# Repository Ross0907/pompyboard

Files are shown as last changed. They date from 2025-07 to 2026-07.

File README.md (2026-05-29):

# Wonkle

WBP logo



Wonkle builds gaming hardware such as tablets and keypads for gamers.
Source code, 3D models, schematics, etc. are available under
[OSI-Approved Software and Hardware Licenses](https://opensource.org/licenses). We welcome everyone
to contribute and join us in our quest to make the best hardware for our fellow gamers.

## [Frequently Asked Questions](https://docs.wonkle.io/faq.html)

## Star History

Star History Chart (https://www.star-history.com/#wonkleio/wonkle&type=date&legend=top-left)

## Contributors

Wonkle is built by people like you.

profile pictures of contributors (https://github.com/wonkleio/wonkle/graphs/contributors)

## License

Different parts of the project are available under different licenses.

All image, audio, and other resources are, unless otherwise specified, available under
[`CC-BY-4.0`](https://spdx.org/licenses/CC-BY-4.0.html).

The hardware designs are, unless otherwise specified, available under
[`CERN-OHL-S-2.0`](https://spdx.org/licenses/CERN-OHL-S-2.0.html).

All other code are, unless otherwise specified, available under
[`MIT`](https://spdx.org/licenses/MIT.html).

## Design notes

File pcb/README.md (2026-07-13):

# PCB

Designed with [KiCad][kicad].

## Designing

- Every PCB is designed with KiCad `v10.0.3`.
- you can learn more about each of the components and read their documentations at
  [`docs/components`](./docs/components/README.md).
  Running `bun run gen-docs` will download PDF documentations.

## Manufacturing

Both prototype and production PCB is manufactured by [JLCPCB][jlcpcb].

### Steps

1. Install [KiCad][kicad].
2. Install the [Fabrication Toolkit][fab-toolkit] plugin.
3. "Generate" production files using the plugin with default settings.
4. Go to [jlcpcb.com][jlcpcb] and click "Add gerber file"
5. Select `pcb/production/wonkle.zip`
6. Configure PCB (you will get 5 pcb of which 2 have components soldered)
   - PCB Specifications
     - PCB Thickness - 1.0mm
     - Surface Finish - LeadFree HASL (health is important boiz)
   - High-spec Options
     - Confirm Production file - Yes
     - Mark on PCB - Order Number(Specify Position)
   - PCB Assembly
     - PCBA Qty - minimum is 2
     - Confirm Parts Placement - Yes
     - Advanced
       - Board Cleaning - Yes
7. Press "NEXT"
8. Inspect PCB and press "NEXT" again
9. Upload and process `pcb/production/bom.csv` and `pcb/production/positions.csv`
10. Review the parts and press "NEXT"
11. Fix component placement
    - only J2 (1x4 pin) needs manual edit
12. Select `Research\Education\DIY\Entertainment > DIY Hobby Circuit Board - HS Code 902300` in Quote & Order section. The total price is 137.13 USD as of writing.
13. Press "SAVE TO CART"
14. Select both PCB and PCBA then click "Secure Checkout"
15. Enter shipping info and follow JLCPCB's instruction (e.g. production file confirmation)
16. Wait for a week and you'll receive your very own board!

[kicad]: https://www.kicad.org/
[jlcpcb]: https://jlcpcb.com/
[fab-toolkit]: https://github.com/bennymeg/Fabrication-Toolkit

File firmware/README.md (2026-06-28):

# Wonkle Firmware

## Must read

- https://probe.rs
- https://github.com/stm32-rs/stm32f4xx-hal
- https://github.com/rust-embedded/cortex-m
- https://defmt.ferrous-systems.com
- https://docs.rust-embedded.org/book
- [`pcb/lib/st-stm32f429/README.md`](../pcb/lib/st-stm32f429/README.md)
- (optional) also check
  - https://github.com/rust-lang/rustlings
  - https://www.youtube.com/@therustybits/videos
  - https://doc.rust-lang.org/stable/book

## Setting up

1. Setup development environment with [mise](https://mise.jdx.dev/getting-started.html) and [nix](https://nix.dev/install-nix.html)
   - [IDE integration](https://mise.jdx.dev/ide-integration.html)

## Commands

### Flash and run

See https://probe.rs/docs/tools/probe-rs/ for more information.
See [`./Cargo.toml`](./Cargo.toml) to see available devices.

Pick a device with `-p <package>`:

```bash
cargo run --release -p wonkleboard-mk1-pro
```

Or from inside a device crate:

```bash
cd device/board/mk1/pro
cargo run --release
```

### List USB devices

```bash
lsusb
```

### Show device descriptor

```bash
lsusb -v -d 1209:02d7 # (vid:pid)
```

### Show HID descriptor

You can use https://eleccelerator.com/usbdescreqparser/ to parse the output.

```bash
usbhid-dump -m 1209:02d7 # (vid:pid)
```

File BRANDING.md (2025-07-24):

# Branding Guideline

## Name

- Correct: PompyBoard / Pompyboard / pompyboard
- not correct: pompy board

## Logo

### Colored

WIP

### Black & White

WIP

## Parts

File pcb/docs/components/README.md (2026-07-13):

<!-- This file is generated by ../../scripts/docs.ts. Do not edit manually. -->

# Component docs

## [AH49HSC](./AH49HSC.md)

## [CD74HC4067SM96](./CD74HC4067SM96.md)

## [STM32F429IGT6](./STM32F429IGT6.md)

## [TPS62152RGTR](./TPS62152RGTR.md)

## [USB4085_GF_A](./USB4085_GF_A.md)

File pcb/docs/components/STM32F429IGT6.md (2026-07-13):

---
documents:
  - label: datasheet
    url: https://web.archive.org/web/20260708092521/https://www.st.com/content/ccc/resource/technical/document/datasheet/03/b4/b2/36/4c/72/49/29/DM00071990.pdf/files/DM000719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
    sha256: fc8828e819fb0717f15c125ae31075c2e48d2afe2eb447e5e0cc1784ddf785bb
  - label: reference manual
    url: https://web.archive.org/web/20260708092558/https://www.st.com/content/ccc/resource/technical/document/reference_manual/3d/6d/5a/66/b4/99/40/d4/DM00031020.pdf/files/D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
    sha256: f3ff2322eec21f4e49081f68481b764506eee81dba6031bc767e2f8955b27cca
  - label: ADC application note
    url: https://web.archive.org/web/20260708092521/https://www.st.com/resource/en/application_note/an2834-how-to-optimize-the-adc-accuracy-in-the-stm32-mcus-stmicroelectroni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
    sha256: da96e285ee1e151646b285e8828b3486ed40bf7ca2680620f06ef693be2cd569
  - label: oscillator application note
    url: https://web.archive.org/web/20260708092522/https://www.st.com/resource/en/application_note/an2867-guidelines-for-oscillator-design-on-stm8afals-and-stm32-mcusmpus-st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
    sha256: 1c92e22e215ca66a159c790589d568830c619d14f31193429787902664eae04e
---

# STM32F429IGT6

In case the links have expired, you can search the documents by their id (in parenthesis) at
[st.com](https://www.st.com/).

- [JLCPCB](https://jlcpcb.com/partdetail/STMicroelectronics-STM32F429IGT6/C54328)

## Datasheet (DS9405)

- see table of contents (page 3) for more info
- page 13 - what the document is
- page 19 - board design
- page 20 - block diagram
- page 26 - power supply
- page 41 - USB
- page 42 - GPIO & ADC
- page 48 - pinout diagram
- page 53 - pinout definitions table
- page 86 - memory mapping
- page 93 - max ranges
- page 95 - operating conditions
- page 101 - supply current
- page 118 - external clock
- page 122 - internal clock
- page 129 - memory
- page 131 - electromagnetic safety
- page 135 - IO ports
- page 152 - USB OTG HS
- page 158 - ADC
- page 163 - PCB design guideline
- page 165 - reference voltage
- page 209 - LQFP176 package
- page 224 - thermal
- page 225 - ordering information
- page 229 - USB OTG HS

## Reference manual (RM0090)

- see table of contents (page 2) for more info
- page 59 - Memory
- page 73 - Flash Memory
- page 113 - CRC
- page 116 - Power
- page 151 - RCC
- page 153 - Clock tree
- page 269 - GPIO
- page 304 - DMA
- page 373 - Interrupts & Events
- page 390 - ADC
- page 480 - LCD-TFT Controller
- page 515 - Timers
- page 960 - USART
- page 1228 - USB OTG_FS
- page 1369 - USB OTG_HS
- page 1671 - Debug

## ADC application note

- see table of contents (page 2) for more info

## Oscillator application note

- see table of contents (page 2) for more info

## ADC pins

ADC-capable GPIO pins taken from datasheet Table 10, pages 53-59.

| Pin  | ADC1 | ADC2 | ADC3 | IN  |
| ---- | :--: | :--: | :--: | :-- |
| PA0  |  ✅  |  ✅  |  ✅  | 0 |
| PA1  |  ✅  |  ✅  |  ✅  | 1 |
| PA2  |  ✅  |  ✅  |  ✅  | 2 |
| PA3  |  ✅  |  ✅  |  ✅  | 3 |
| PA4  |  ✅  |  ✅  | | 4 |
| PA5  |  ✅  |  ✅  | | 5 |
| PA6  |  ✅  |  ✅  | | 6 |
| PA7  |  ✅  |  ✅  | | 7 |
| PB0  |  ✅  |  ✅  | | 8 |
| PB1  |  ✅  |  ✅  | | 9 |
| PC0  |  ✅  |  ✅  |  ✅  | 10  |
| PC1  |  ✅  |  ✅  |  ✅  | 11  |
| PC2  |  ✅  |  ✅  |  ✅  | 12  |
| PC3  |  ✅  |  ✅  |  ✅  | 13  |
| PC4  |  ✅  |  ✅  | | 14  |
| PC5  |  ✅  |  ✅  | | 15  |
| PF3  | | |  ✅  | 9 |
| PF4  | | |  ✅  | 14  |
| PF5  | | |  ✅  | 15  |
| PF6  | | |  ✅  | 4 |
| PF7  | | |  ✅  | 5 |
| PF8  | | |  ✅  | 6 |
| PF9  | | |  ✅  | 7 |
| PF10 | | |  ✅  | 8 |

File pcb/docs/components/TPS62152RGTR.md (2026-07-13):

---
documents:
  - label: datasheet
    url: https://www.ti.com/lit/ds/symlink/tps62152.pdf
    sha256: 81e0acf0290ce9d8b54f53af5edd4540a8b69e765809abd9c209f1089777875b
---

# TPS62152RGTR

- [JLCPCB](https://jlcpcb.com/partdetail/TexasInstruments-TPS62152RGTR/C2070611)

## Datasheet

- page 3 - pinout
- page 4 - specifications
- page 18 - application curves
- page 22 - Power-Supply Rejection Ratio (PSRR)
- page 26 - 3.3V 1A example schematic
- page 28 - PCB layout guideline and example

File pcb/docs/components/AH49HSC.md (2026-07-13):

---
documents:
  - label: datasheet
    url: https://jlcpcb.com/api/file/downloadByFileSystemAccessId/8588913960356106240
    sha256: 8531c6d96742387937d8e28dc8df8cf026d0c4049aeb09b5ba732353a892300a
---

# AH49HSC

- [JLCPCB](https://jlcpcb.com/partdetail/PJSEMI-AH49HSC/C510723)

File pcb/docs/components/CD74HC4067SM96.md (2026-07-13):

---
documents:
  - label: datasheet
    url: https://www.ti.com/lit/ds/symlink/cd74hc4067.pdf
    sha256: fa6b802d8ad556b5e13ad05808e3feb5ef3824e0803dab9d12978de9b0e67b24
---

# CD74HC4067SM96

- [JLCPCB](https://jlcpcb.com/partdetail/TexasInstruments-CD74HC4067SM96/C98457)

## Datasheet

- page 1 - pinout
- page 2 - truth table

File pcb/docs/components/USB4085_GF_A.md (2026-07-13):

---
documents:
  - label: datasheet
    url: https://gct.co/download?type=PDFSpecification&name=usb4085-spec.pdf
    sha256: e5e6f4f67ccaee397b33324fde439f7cdd273c5dd9048c48f096aae7029034be
---

# USB4085_GF_A

- [JLCPCB](https://jlcpcb.com/partdetail/8061907-USB4085_GFA/C7095263)

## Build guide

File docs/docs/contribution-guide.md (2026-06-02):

# Contribution Guide

## Project overview

Wonkle projects can be roughly broken down into 5 parts:

- [PCB](https://github.com/wonkleio/wonkle/tree/dev/pcb) - Electronics that powers the device
- [Firmware](https://github.com/wonkleio/wonkle/tree/dev/firmware) - Software that controls the electronics
- [3D models](https://github.com/wonkleio/wonkle/tree/dev/3d) - Designs for the 3D-printed case
- [Driver](https://github.com/wonkleio/OpenTabletDriver) - Device driver that allows you to use the
- [Website](https://github.com/wonkleio/wonkle/tree/dev/web) - Website for purchasing and configuring the device
- [Docs](https://github.com/wonkleio/wonkle/tree/dev/docs) - Information & Resources (hint: You are reading it)

## Setting up development environment

### For tablet driver

1. Clone the git repository
   ```bash
   git clone https://github.com/wonkleio/OpenTabletDriver
   ```
2. Follow [`CONTRIBUTING.md`](https://github.com/wonkleio/OpenTabletDriver/blob/master/CONTRIBUTING.md)
3. Send Pull request to `master` branch when contributing

### For everything else

1. Clone the git repository
   ```bash
   git clone https://github.com/wonkleio/wonkle
   ```
2. Follow `README.md` of the sub-project you want to work on
   (e.g. [`docs/README.md`](https://github.com/wonkleio/wonkle/tree/dev/docs))
3. Send pull request to `dev` branch when contributing

## Contribution standards

### AI

- ✅ OK - Using AI to write code
- ✅ OK - Using AI to help you analyze/understand
- ❌ NOT OK - Using AI to write natural language
  - This applies to, but not limited to code comments, HTML contents,
    documentations, commit messages, and Pull request descriptions
- ❌ NOT OK - Using AI to make slop
  - **1 year ban from the project for repeated violations**
  - Please review your changes before sending a pull request.

### Communication, communication, communication

Remember, people can't read your mind. If you did something amazing and you want others to care
about it, explain your intent and motivation using fact and logic so anyone with three digit IQ can
understand them. You don't necessarily have to dumb things down. Just be clear about it.

### Formatting

All text-based files must be formatted using the correct formatter.
See [`.vscode/settings.json`](https://github.com/wonkleio/wonkle/blob/dev/.vscode/settings.json)
for more info.

### line length

All human-written text files must have 100 characters or less per line unless absolutely necessary.
If you're using vscode, you should see a vertical line (ruler) that shows you where the limit is.

### Commits messages

Commit messages must be specific and concise. Prepend scope if necessary.

For example:

- `remove unused files`
- `firmware: add more test cases for functionName`
- `web: bump packageName version from v6 to v9`

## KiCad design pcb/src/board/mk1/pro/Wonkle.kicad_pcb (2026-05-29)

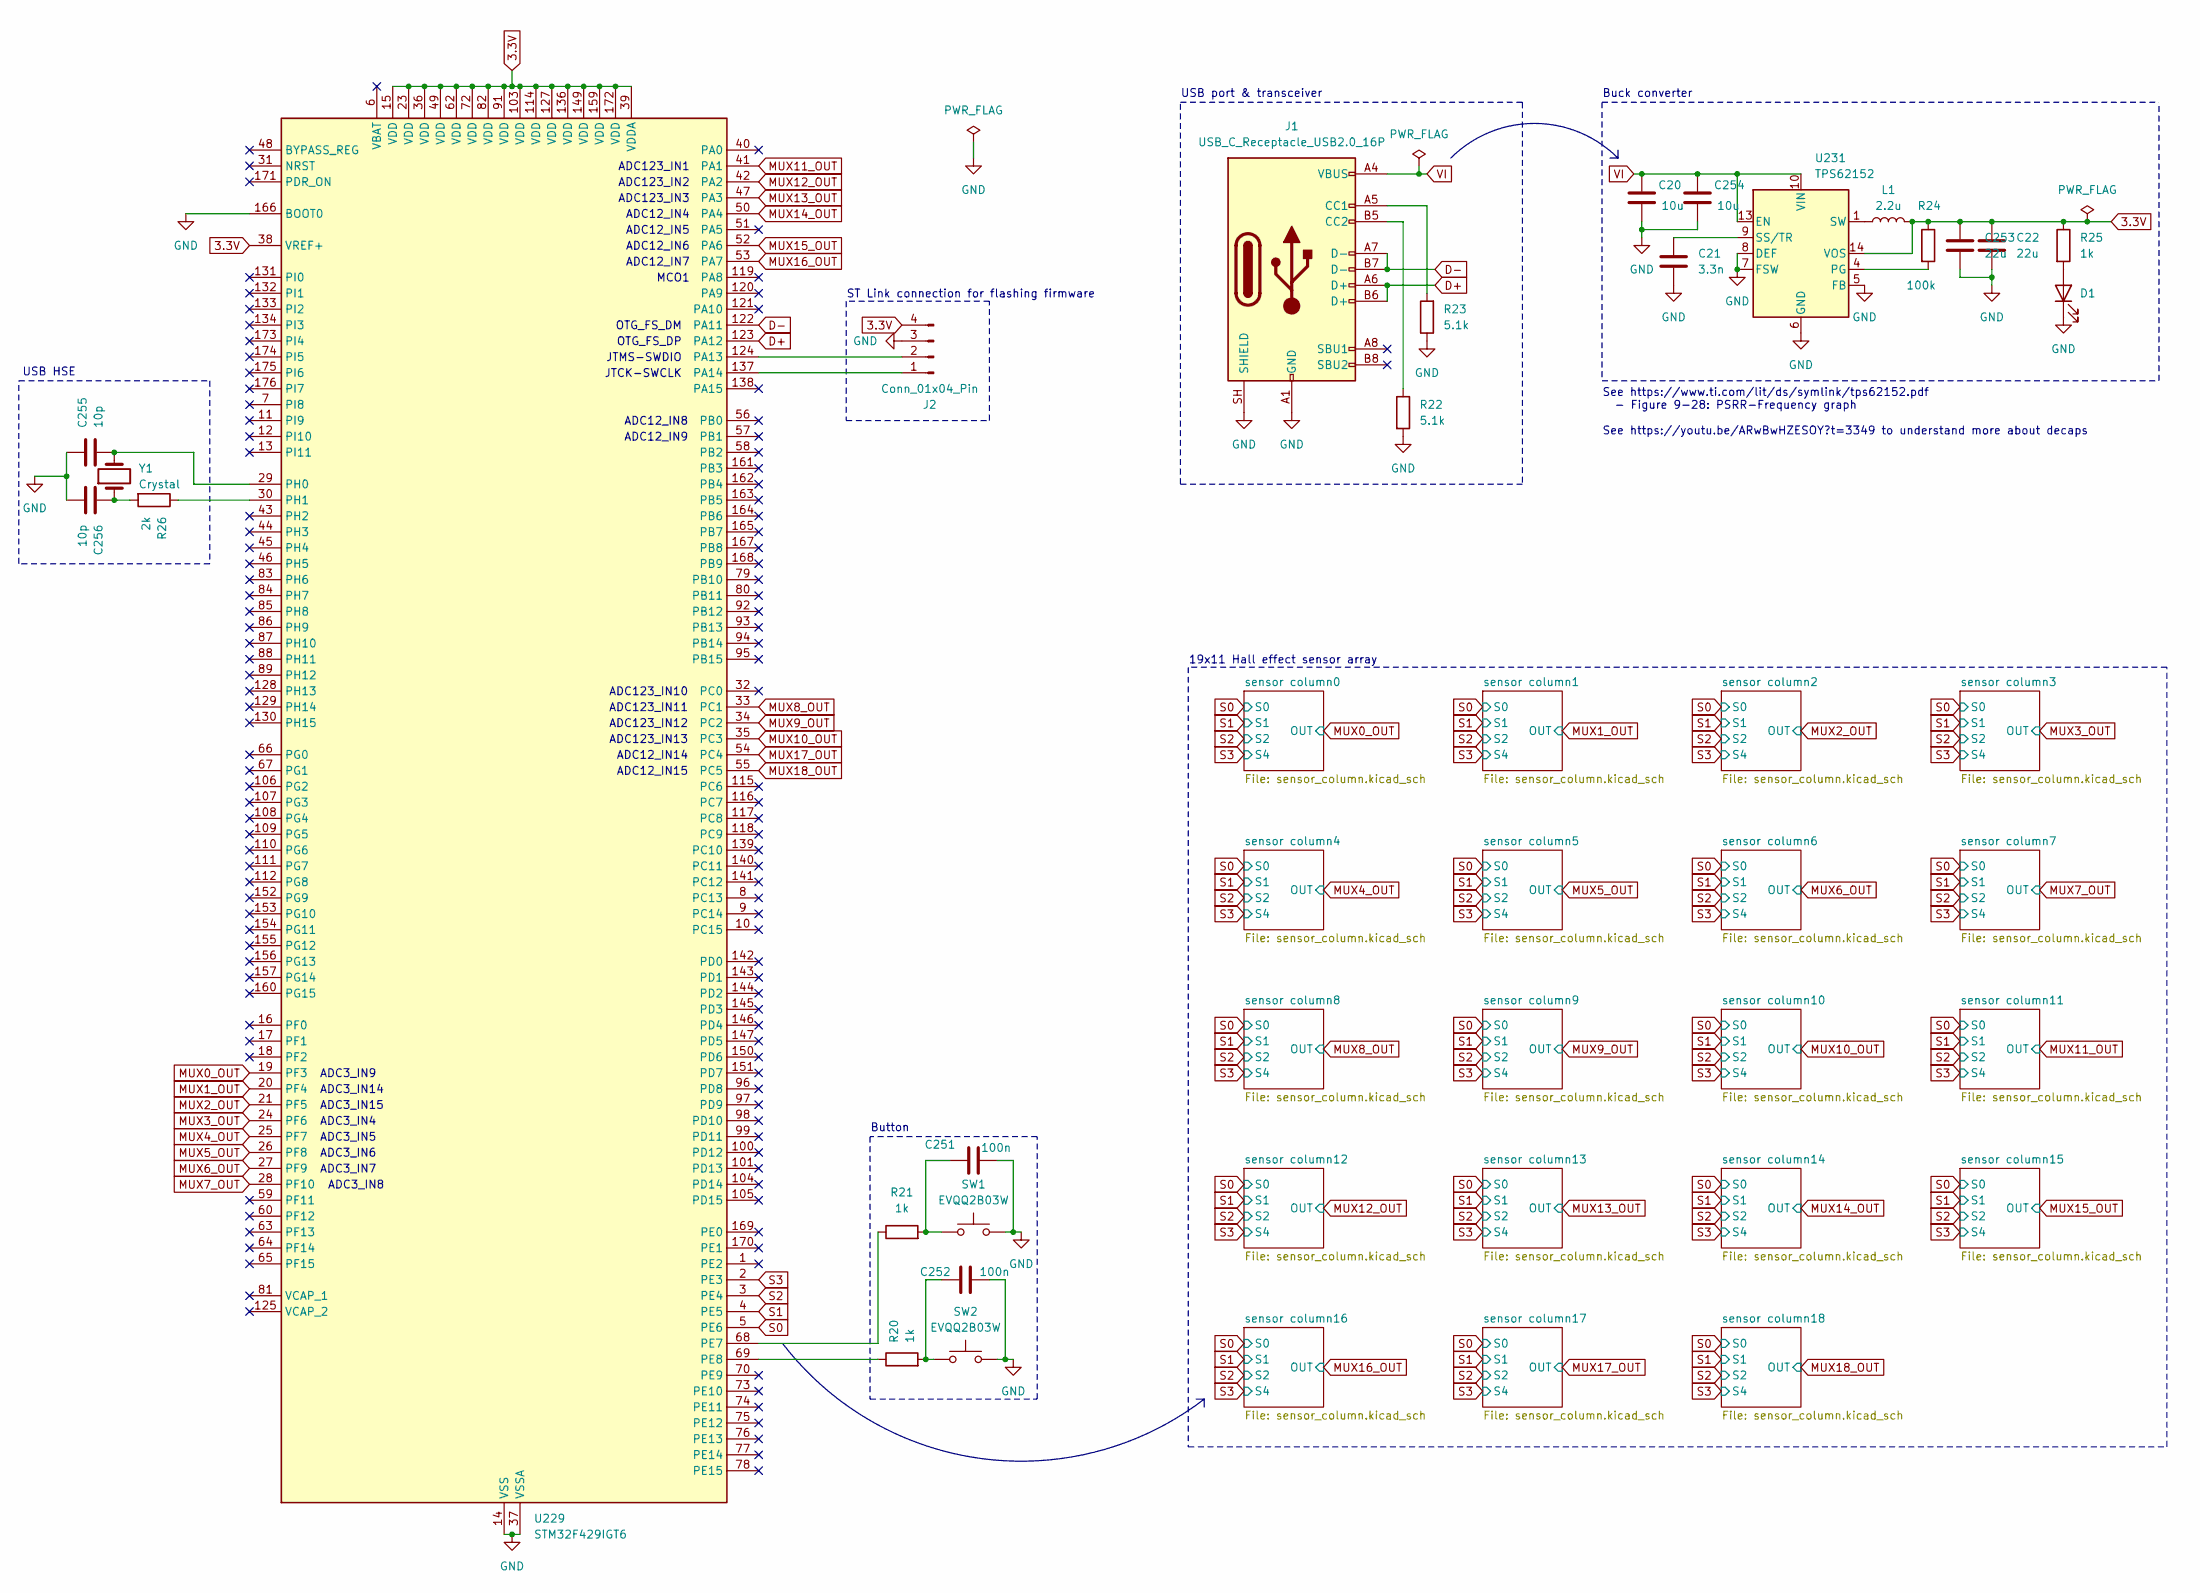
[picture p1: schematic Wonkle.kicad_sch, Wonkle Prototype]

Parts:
C20, C254: 10u; C_0402_1005Metric; LCSC Part # C315248
C21: 3.3n; C_0402_1005Metric; LCSC Part # C3881585
C22, C253: 22u; C_0402_1005Metric; LCSC Part # C105226
C251, C252: 100n; C_0402_1005Metric; LCSC Part # C1525
C255, C256: 10p; C_0402_1005Metric; LCSC Part # C1525
D1: F.0603.00139/P2-0603R1TS2-06T-002; LED_0603_1608Metric; LCSC Part # C7496820
J1: USB_C_Receptacle_USB2.0_16P; USB_C_Receptacle_GCT_USB4085; LCSC Part # C7095263
J2: Conn_01x04_Pin; PinHeader_1x04_P2.54mm_Horizontal; LCSC Part # C32713263
L1: 2.2u; L_Coilcraft_XxL4020; LCSC Part # C122469
R20, R21: 1k; R_0402_1005Metric; LCSC Part # C25744
R22, R23: 5.1k; R_0402_1005Metric; LCSC Part # C25905
R24: 100k; R_0603_1608Metric; LCSC Part # C22369815
R25: 1k; R_0402_1005Metric; LCSC Part # C11702
R26: 2k; R_0402_1005Metric; LCSC Part # C11702
SW1, SW2: EVQQ2B03W; SW_SPST_EVQQ2; LCSC Part # C79178
U229: STM32F429IGT6; LQFP-176_24x24mm_P0.5mm
U231: TPS62152; VQFN-16-1EP_3x3mm_P0.5mm_EP1.68x1.68mm_ThermalVias; LCSC Part # C2070611
Y1: Crystal; Crystal_SMD_5032-2Pin_5.0x3.2mm

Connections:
3.3V: C22.1, C253.1, J2.4, L1.2, R24.1, R25.1, U229.15 (VDD), U229.23 (VDD), U229.36 (VDD), U229.38 (VREF+), U229.39 (VDDA), U229.49 (VDD), U229.62 (VDD), U229.72 (VDD), U229.82 (VDD), U229.91 (VDD), U229.103 (VDD), U229.114 (VDD), U229.127 (VDD), U229.136 (VDD), U229.149 (VDD), U229.159 (VDD), U229.172 (VDD), U231.14 (VOS); also elsewhere on the board
D+: J1.A6 (D+), J1.B6 (D+), U229.123 (PA12)
D-: J1.A7 (D-), J1.B7 (D-), U229.122 (PA11)
GND: C20.2, C21.2, C22.2, C251.2, C252.2, C253.2, C254.2, C255.1, C256.2, D1.1 (K), J1.A1 (GND), J1.A12 (GND), J1.B1 (GND), J1.B12 (GND), J1.SH (SHIELD), J2.3, R22.2, R23.1, SW1.2, SW2.2, U229.14 (VSS), U229.22 (VSS), U229.37 (VSSA), U229.61 (VSS), U229.71 (VSS), U229.90 (VSS), U229.102 (VSS), U229.113 (VSS), U229.126 (VSS), U229.135 (VSS), U229.148 (VSS), U229.158 (VSS), U229.166 (BOOT0), U231.5 (FB), U231.6 (GND), U231.7 (FSW), U231.8 (DEF), U231.15 (GND), U231.16 (GND), U231.17 (GND); also elsewhere on the board
MUX0_OUT: U229.19 (PF3); also elsewhere on the board
MUX1_OUT: U229.20 (PF4); also elsewhere on the board
MUX2_OUT: U229.21 (PF5); also elsewhere on the board
MUX3_OUT: U229.24 (PF6); also elsewhere on the board
MUX4_OUT: U229.25 (PF7); also elsewhere on the board
MUX5_OUT: U229.26 (PF8); also elsewhere on the board
MUX6_OUT: U229.27 (PF9); also elsewhere on the board
MUX7_OUT: U229.28 (PF10); also elsewhere on the board
MUX8_OUT: U229.33 (PC1); also elsewhere on the board
MUX9_OUT: U229.34 (PC2); also elsewhere on the board
MUX10_OUT: U229.35 (PC3); also elsewhere on the board
MUX11_OUT: U229.41 (PA1); also elsewhere on the board
MUX12_OUT: U229.42 (PA2); also elsewhere on the board
MUX13_OUT: U229.47 (PA3); also elsewhere on the board
MUX14_OUT: U229.50 (PA4); also elsewhere on the board
MUX15_OUT: U229.52 (PA6); also elsewhere on the board
MUX16_OUT: U229.53 (PA7); also elsewhere on the board
MUX17_OUT: U229.54 (PC4); also elsewhere on the board
MUX18_OUT: U229.55 (PC5); also elsewhere on the board
unnamed: C251.1, R21.2, SW1.1
unnamed: C252.1, R20.2, SW2.1
unnamed: C256.1, R26.2, Y1.1
unnamed: D1.2 (A), R25.2
unnamed: J1.A5 (CC1), R23.2
unnamed: J1.B5 (CC2), R22.1
unnamed: J2.1, U229.137 (PA14)
unnamed: J2.2, U229.124 (PA13)
unnamed: L1.1, U231.1 (SW), U231.2 (SW), U231.3 (SW)
unnamed: R21.1, U229.68 (PE7)
unnamed: R20.1, U229.69 (PE8)
unnamed: C255.2, U229.29 (PH0), Y1.2
unnamed: R26.1, U229.30 (PH1)
unnamed: R24.2, U231.4 (PG)
unnamed: C21.1, U231.9 (SS/TR)
S0: U229.5 (PE6); also elsewhere on the board
S1: U229.4 (PE5); also elsewhere on the board
S2: U229.3 (PE4); also elsewhere on the board
S3: U229.2 (PE3); also elsewhere on the board
VI: C20.1, C254.1, J1.A4 (VBUS), J1.A9 (VBUS), J1.B4 (VBUS), J1.B9 (VBUS), U231.10 (VIN), U231.11 (VIN), U231.12 (VIN), U231.13 (EN)

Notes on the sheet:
ADC3_IN6
ADC3_IN8
ADC12_IN15
ADC3_IN14
ADC12_IN14
ADC123_IN10
ADC123_IN12
Button
ADC12_IN9
ADC3_IN15
OTG_FS_DM
ADC3_IN4
See https://www.ti.com/lit/ds/symlink/tps62152.pdf - Figure 9-28: PSRR-Frequency graph See https://youtu.be/ARwBwHZESOY?t=3349 to understand more about decaps
USB HSE
ADC12_IN4
Buck converter
19x11 Hall effect sensor array
ADC3_IN9
ADC123_IN1
ADC123_IN13
ADC12_IN6
ADC3_IN5
ADC12_IN5
ST Link connection for flashing firmware
JTCK-SWCLK
USB port & transceiver
OTG_FS_DP
MCO1
ADC123_IN11
ADC12_IN8
ADC12_IN7
JTMS-SWDIO
ADC123_IN3
ADC123_IN2
ADC3_IN7

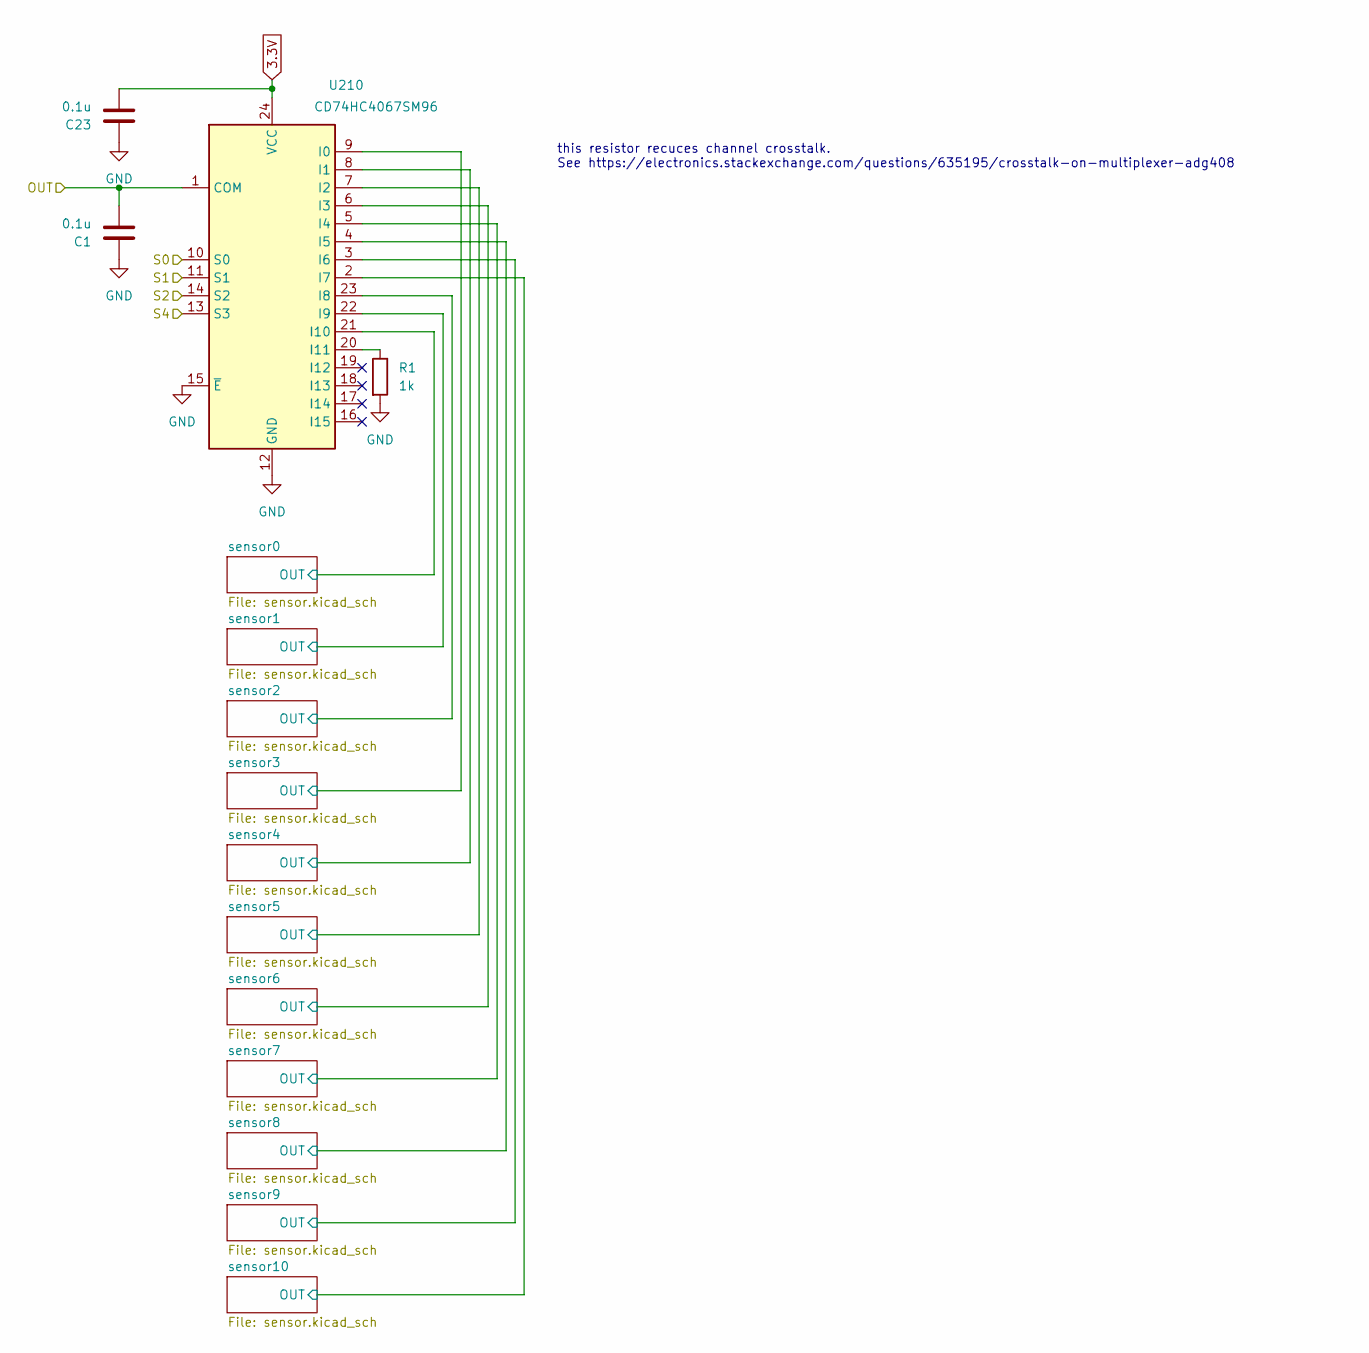
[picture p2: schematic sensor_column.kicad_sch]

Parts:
C1, C23: 0.1u; C_0402_1005Metric; LCSC Part # C1525
R1: 1k; R_0402_1005Metric; LCSC Part # C11702
U210: CD74HC4067SM96; SSOP-24_5.3x8.2mm_P0.65mm

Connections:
3.3V: C23.2, U210.24 (VCC); also elsewhere on the board
/sensor column0/sensor0/OUT: U210.21 (I10); also elsewhere on the board
/sensor column0/sensor1/OUT: U210.22 (I9); also elsewhere on the board
/sensor column0/sensor2/OUT: U210.23 (I8); also elsewhere on the board
/sensor column0/sensor3/OUT: U210.9 (I0); also elsewhere on the board
/sensor column0/sensor4/OUT: U210.8 (I1); also elsewhere on the board
/sensor column0/sensor5/OUT: U210.7 (I2); also elsewhere on the board
/sensor column0/sensor6/OUT: U210.6 (I3); also elsewhere on the board
/sensor column0/sensor7/OUT: U210.5 (I4); also elsewhere on the board
/sensor column0/sensor8/OUT: U210.4 (I5); also elsewhere on the board
/sensor column0/sensor9/OUT: U210.3 (I6); also elsewhere on the board
/sensor column0/sensor10/OUT: U210.2 (I7); also elsewhere on the board
GND: C1.1, C23.1, R1.2, U210.12 (GND), U210.15 (~E); also elsewhere on the board
MUX0_OUT: C1.2, U210.1 (COM); also elsewhere on the board
unnamed: R1.1, U210.20 (I11)
S0: U210.10 (S0); also elsewhere on the board
S1: U210.11 (S1); also elsewhere on the board
S2: U210.14 (S2); also elsewhere on the board
S3: U210.13 (S3); also elsewhere on the board

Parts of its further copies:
C2, C3, C4, C5, C6, C7, C8, C9, C10, C11, C12, C13, C14, C15, C16, C17, C18, C19, C24, C25, C26, C27, C28, C29, C30, C31, C32, C33, C34, C35, C36, C37, C38, C39, C40, C41: 0.1u; C_0402_1005Metric; LCSC Part # C1525
R2, R3, R4, R5, R6, R7, R8, R9, R10, R11, R12, R13, R14, R15, R16, R17, R18, R19: 1k; R_0402_1005Metric; LCSC Part # C11702
U211, U212, U213, U214, U215, U216, U217, U218, U219, U220, U221, U222, U223, U224, U225, U226, U227, U228: CD74HC4067SM96; SSOP-24_5.3x8.2mm_P0.65mm

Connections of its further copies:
3.3V: C24.2, C25.2, C26.2, C27.2, C28.2, C29.2, C30.2, C31.2, C32.2, C33.2, C34.2, C35.2, C36.2, C37.2, C38.2, C39.2, C40.2, C41.2, U211.24 (VCC), U212.24 (VCC), U213.24 (VCC), U214.24 (VCC), U215.24 (VCC), U216.24 (VCC), U217.24 (VCC), U218.24 (VCC), U219.24 (VCC), U220.24 (VCC), U221.24 (VCC), U222.24 (VCC), U223.24 (VCC), U224.24 (VCC), U225.24 (VCC), U226.24 (VCC), U227.24 (VCC), U228.24 (VCC); also elsewhere on the board
/sensor column1/sensor0/OUT: U211.21 (I10); also elsewhere on the board
/sensor column1/sensor1/OUT: U211.22 (I9); also elsewhere on the board
/sensor column1/sensor2/OUT: U211.23 (I8); also elsewhere on the board
/sensor column1/sensor3/OUT: U211.9 (I0); also elsewhere on the board
/sensor column1/sensor4/OUT: U211.8 (I1); also elsewhere on the board
/sensor column1/sensor5/OUT: U211.7 (I2); also elsewhere on the board
/sensor column1/sensor6/OUT: U211.6 (I3); also elsewhere on the board
/sensor column1/sensor7/OUT: U211.5 (I4); also elsewhere on the board
/sensor column1/sensor8/OUT: U211.4 (I5); also elsewhere on the board
/sensor column1/sensor9/OUT: U211.3 (I6); also elsewhere on the board
/sensor column1/sensor10/OUT: U211.2 (I7); also elsewhere on the board
/sensor column2/sensor0/OUT: U212.21 (I10); also elsewhere on the board
/sensor column2/sensor1/OUT: U212.22 (I9); also elsewhere on the board
/sensor column2/sensor2/OUT: U212.23 (I8); also elsewhere on the board
/sensor column2/sensor3/OUT: U212.9 (I0); also elsewhere on the board
/sensor column2/sensor4/OUT: U212.8 (I1); also elsewhere on the board
/sensor column2/sensor5/OUT: U212.7 (I2); also elsewhere on the board
/sensor column2/sensor6/OUT: U212.6 (I3); also elsewhere on the board
/sensor column2/sensor7/OUT: U212.5 (I4); also elsewhere on the board
/sensor column2/sensor8/OUT: U212.4 (I5); also elsewhere on the board
/sensor column2/sensor9/OUT: U212.3 (I6); also elsewhere on the board
/sensor column2/sensor10/OUT: U212.2 (I7); also elsewhere on the board
/sensor column3/sensor0/OUT: U213.21 (I10); also elsewhere on the board
/sensor column3/sensor1/OUT: U213.22 (I9); also elsewhere on the board
/sensor column3/sensor2/OUT: U213.23 (I8); also elsewhere on the board
/sensor column3/sensor3/OUT: U213.9 (I0); also elsewhere on the board
/sensor column3/sensor4/OUT: U213.8 (I1); also elsewhere on the board
/sensor column3/sensor5/OUT: U213.7 (I2); also elsewhere on the board
/sensor column3/sensor6/OUT: U213.6 (I3); also elsewhere on the board
/sensor column3/sensor7/OUT: U213.5 (I4); also elsewhere on the board
/sensor column3/sensor8/OUT: U213.4 (I5); also elsewhere on the board
/sensor column3/sensor9/OUT: U213.3 (I6); also elsewhere on the board
/sensor column3/sensor10/OUT: U213.2 (I7); also elsewhere on the board
/sensor column4/sensor0/OUT: U214.21 (I10); also elsewhere on the board
/sensor column4/sensor1/OUT: U214.22 (I9); also elsewhere on the board
/sensor column4/sensor2/OUT: U214.23 (I8); also elsewhere on the board
/sensor column4/sensor3/OUT: U214.9 (I0); also elsewhere on the board
/sensor column4/sensor4/OUT: U214.8 (I1); also elsewhere on the board
/sensor column4/sensor5/OUT: U214.7 (I2); also elsewhere on the board
/sensor column4/sensor6/OUT: U214.6 (I3); also elsewhere on the board
/sensor column4/sensor7/OUT: U214.5 (I4); also elsewhere on the board
/sensor column4/sensor8/OUT: U214.4 (I5); also elsewhere on the board
/sensor column4/sensor9/OUT: U214.3 (I6); also elsewhere on the board
/sensor column4/sensor10/OUT: U214.2 (I7); also elsewhere on the board
/sensor column5/sensor0/OUT: U215.21 (I10); also elsewhere on the board
/sensor column5/sensor1/OUT: U215.22 (I9); also elsewhere on the board
/sensor column5/sensor2/OUT: U215.23 (I8); also elsewhere on the board
/sensor column5/sensor3/OUT: U215.9 (I0); also elsewhere on the board
/sensor column5/sensor4/OUT: U215.8 (I1); also elsewhere on the board
/sensor column5/sensor5/OUT: U215.7 (I2); also elsewhere on the board
/sensor column5/sensor6/OUT: U215.6 (I3); also elsewhere on the board
/sensor column5/sensor7/OUT: U215.5 (I4); also elsewhere on the board
/sensor column5/sensor8/OUT: U215.4 (I5); also elsewhere on the board
/sensor column5/sensor9/OUT: U215.3 (I6); also elsewhere on the board
/sensor column5/sensor10/OUT: U215.2 (I7); also elsewhere on the board
/sensor column6/sensor0/OUT: U216.21 (I10); also elsewhere on the board
/sensor column6/sensor1/OUT: U216.22 (I9); also elsewhere on the board
/sensor column6/sensor2/OUT: U216.23 (I8); also elsewhere on the board
/sensor column6/sensor3/OUT: U216.9 (I0); also elsewhere on the board
/sensor column6/sensor4/OUT: U216.8 (I1); also elsewhere on the board
/sensor column6/sensor5/OUT: U216.7 (I2); also elsewhere on the board
/sensor column6/sensor6/OUT: U216.6 (I3); also elsewhere on the board
/sensor column6/sensor7/OUT: U216.5 (I4); also elsewhere on the board
/sensor column6/sensor8/OUT: U216.4 (I5); also elsewhere on the board
/sensor column6/sensor9/OUT: U216.3 (I6); also elsewhere on the board
/sensor column6/sensor10/OUT: U216.2 (I7); also elsewhere on the board
/sensor column7/sensor0/OUT: U217.21 (I10); also elsewhere on the board
/sensor column7/sensor1/OUT: U217.22 (I9); also elsewhere on the board
/sensor column7/sensor2/OUT: U217.23 (I8); also elsewhere on the board
/sensor column7/sensor3/OUT: U217.9 (I0); also elsewhere on the board
/sensor column7/sensor4/OUT: U217.8 (I1); also elsewhere on the board
/sensor column7/sensor5/OUT: U217.7 (I2); also elsewhere on the board
/sensor column7/sensor6/OUT: U217.6 (I3); also elsewhere on the board
/sensor column7/sensor7/OUT: U217.5 (I4); also elsewhere on the board
/sensor column7/sensor8/OUT: U217.4 (I5); also elsewhere on the board
/sensor column7/sensor9/OUT: U217.3 (I6); also elsewhere on the board
/sensor column7/sensor10/OUT: U217.2 (I7); also elsewhere on the board
/sensor column8/sensor0/OUT: U218.21 (I10); also elsewhere on the board
/sensor column8/sensor1/OUT: U218.22 (I9); also elsewhere on the board
/sensor column8/sensor2/OUT: U218.23 (I8); also elsewhere on the board
/sensor column8/sensor3/OUT: U218.9 (I0); also elsewhere on the board
/sensor column8/sensor4/OUT: U218.8 (I1); also elsewhere on the board
/sensor column8/sensor5/OUT: U218.7 (I2); also elsewhere on the board
/sensor column8/sensor6/OUT: U218.6 (I3); also elsewhere on the board
/sensor column8/sensor7/OUT: U218.5 (I4); also elsewhere on the board
/sensor column8/sensor8/OUT: U218.4 (I5); also elsewhere on the board
/sensor column8/sensor9/OUT: U218.3 (I6); also elsewhere on the board
/sensor column8/sensor10/OUT: U218.2 (I7); also elsewhere on the board
/sensor column9/sensor0/OUT: U219.21 (I10); also elsewhere on the board
/sensor column9/sensor1/OUT: U219.22 (I9); also elsewhere on the board
/sensor column9/sensor2/OUT: U219.23 (I8); also elsewhere on the board
/sensor column9/sensor3/OUT: U219.9 (I0); also elsewhere on the board
/sensor column9/sensor4/OUT: U219.8 (I1); also elsewhere on the board
/sensor column9/sensor5/OUT: U219.7 (I2); also elsewhere on the board
/sensor column9/sensor6/OUT: U219.6 (I3); also elsewhere on the board
/sensor column9/sensor7/OUT: U219.5 (I4); also elsewhere on the board
/sensor column9/sensor8/OUT: U219.4 (I5); also elsewhere on the board
/sensor column9/sensor9/OUT: U219.3 (I6); also elsewhere on the board
/sensor column9/sensor10/OUT: U219.2 (I7); also elsewhere on the board
/sensor column10/sensor0/OUT: U220.21 (I10); also elsewhere on the board
/sensor column10/sensor1/OUT: U220.22 (I9); also elsewhere on the board
/sensor column10/sensor2/OUT: U220.23 (I8); also elsewhere on the board
/sensor column10/sensor3/OUT: U220.9 (I0); also elsewhere on the board
/sensor column10/sensor4/OUT: U220.8 (I1); also elsewhere on the board
/sensor column10/sensor5/OUT: U220.7 (I2); also elsewhere on the board
/sensor column10/sensor6/OUT: U220.6 (I3); also elsewhere on the board
/sensor column10/sensor7/OUT: U220.5 (I4); also elsewhere on the board
/sensor column10/sensor8/OUT: U220.4 (I5); also elsewhere on the board
/sensor column10/sensor9/OUT: U220.3 (I6); also elsewhere on the board
/sensor column10/sensor10/OUT: U220.2 (I7); also elsewhere on the board
/sensor column11/sensor0/OUT: U221.21 (I10); also elsewhere on the board
/sensor column11/sensor1/OUT: U221.22 (I9); also elsewhere on the board
/sensor column11/sensor2/OUT: U221.23 (I8); also elsewhere on the board
/sensor column11/sensor3/OUT: U221.9 (I0); also elsewhere on the board
/sensor column11/sensor4/OUT: U221.8 (I1); also elsewhere on the board
/sensor column11/sensor5/OUT: U221.7 (I2); also elsewhere on the board
/sensor column11/sensor6/OUT: U221.6 (I3); also elsewhere on the board
/sensor column11/sensor7/OUT: U221.5 (I4); also elsewhere on the board
/sensor column11/sensor8/OUT: U221.4 (I5); also elsewhere on the board
/sensor column11/sensor9/OUT: U221.3 (I6); also elsewhere on the board
/sensor column11/sensor10/OUT: U221.2 (I7); also elsewhere on the board
/sensor column12/sensor0/OUT: U222.21 (I10); also elsewhere on the board
/sensor column12/sensor1/OUT: U222.22 (I9); also elsewhere on the board
/sensor column12/sensor2/OUT: U222.23 (I8); also elsewhere on the board
/sensor column12/sensor3/OUT: U222.9 (I0); also elsewhere on the board
/sensor column12/sensor4/OUT: U222.8 (I1); also elsewhere on the board
/sensor column12/sensor5/OUT: U222.7 (I2); also elsewhere on the board
/sensor column12/sensor6/OUT: U222.6 (I3); also elsewhere on the board
/sensor column12/sensor7/OUT: U222.5 (I4); also elsewhere on the board
/sensor column12/sensor8/OUT: U222.4 (I5); also elsewhere on the board
/sensor column12/sensor9/OUT: U222.3 (I6); also elsewhere on the board
/sensor column12/sensor10/OUT: U222.2 (I7); also elsewhere on the board
/sensor column13/sensor0/OUT: U223.21 (I10); also elsewhere on the board
/sensor column13/sensor1/OUT: U223.22 (I9); also elsewhere on the board
/sensor column13/sensor2/OUT: U223.23 (I8); also elsewhere on the board
/sensor column13/sensor3/OUT: U223.9 (I0); also elsewhere on the board
/sensor column13/sensor4/OUT: U223.8 (I1); also elsewhere on the board
/sensor column13/sensor5/OUT: U223.7 (I2); also elsewhere on the board
/sensor column13/sensor6/OUT: U223.6 (I3); also elsewhere on the board
/sensor column13/sensor7/OUT: U223.5 (I4); also elsewhere on the board
/sensor column13/sensor8/OUT: U223.4 (I5); also elsewhere on the board
/sensor column13/sensor9/OUT: U223.3 (I6); also elsewhere on the board
/sensor column13/sensor10/OUT: U223.2 (I7); also elsewhere on the board
/sensor column14/sensor0/OUT: U224.21 (I10); also elsewhere on the board
/sensor column14/sensor1/OUT: U224.22 (I9); also elsewhere on the board
/sensor column14/sensor2/OUT: U224.23 (I8); also elsewhere on the board
/sensor column14/sensor3/OUT: U224.9 (I0); also elsewhere on the board
/sensor column14/sensor4/OUT: U224.8 (I1); also elsewhere on the board
/sensor column14/sensor5/OUT: U224.7 (I2); also elsewhere on the board
/sensor column14/sensor6/OUT: U224.6 (I3); also elsewhere on the board
/sensor column14/sensor7/OUT: U224.5 (I4); also elsewhere on the board
/sensor column14/sensor8/OUT: U224.4 (I5); also elsewhere on the board
/sensor column14/sensor9/OUT: U224.3 (I6); also elsewhere on the board
/sensor column14/sensor10/OUT: U224.2 (I7); also elsewhere on the board
/sensor column15/sensor0/OUT: U225.21 (I10); also elsewhere on the board
/sensor column15/sensor1/OUT: U225.22 (I9); also elsewhere on the board
/sensor column15/sensor2/OUT: U225.23 (I8); also elsewhere on the board
/sensor column15/sensor3/OUT: U225.9 (I0); also elsewhere on the board
/sensor column15/sensor4/OUT: U225.8 (I1); also elsewhere on the board
/sensor column15/sensor5/OUT: U225.7 (I2); also elsewhere on the board
/sensor column15/sensor6/OUT: U225.6 (I3); also elsewhere on the board
/sensor column15/sensor7/OUT: U225.5 (I4); also elsewhere on the board
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

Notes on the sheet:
this resistor recuces channel crosstalk. See https://electronics.stackexchange.com/questions/635195/crosstalk-on-multiplexer-adg408

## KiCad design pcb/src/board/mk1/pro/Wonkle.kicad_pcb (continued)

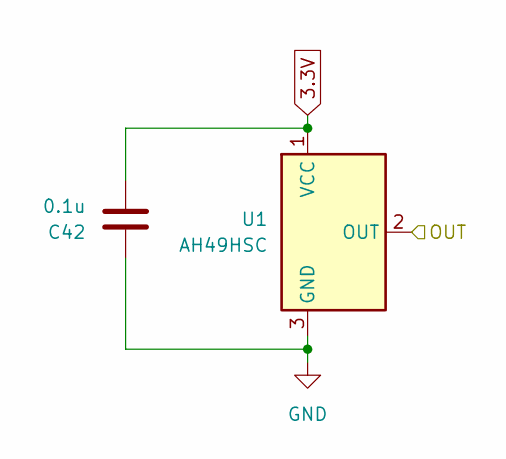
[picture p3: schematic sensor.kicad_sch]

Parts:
C42: 0.1u; C_0402_1005Metric; LCSC Part # C1525
U1: AH49HSC; SOT-23-3; LCSC Part # C510723

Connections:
3.3V: C42.2, U1.1 (VCC); also elsewhere on the board
/sensor column0/sensor0/OUT: U1.2 (OUT); also elsewhere on the board
GND: C42.1, U1.3 (GND); also elsewhere on the board

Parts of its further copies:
C43, C44, C45, C46, C47, C48, C49, C50, C51, C52, C53, C54, C55, C56, C57, C58, C59, C60, C61, C62, C63, C64, C65, C66, C67, C68, C69, C70, C71, C72, C73, C74, C75, C76, C77, C78, C79, C80, C81, C82, C83, C84, C85, C86, C87, C88, C89, C90, C91, C92, C93, C94, C95, C96, C97, C98, C99, C100, C101, C102, C103, C104, C105, C106, C107, C108, C109, C110, C111, C112, C113, C114, C115, C116, C117, C118, C119, C120, C121, C122, C123, C124, C125, C126, C127, C128, C129, C130, C131, C132, C133, C134, C135, C136, C137, C138, C139, C140, C141, C142, C143, C144, C145, C146, C147, C148, C149, C150, C151, C152, C153, C154, C155, C156, C157, C158, C159, C160, C161, C162, C163, C164, C165, C166, C167, C168, C169, C170, C171, C172, C173, C174, C175, C176, C177, C178, C179, C180, C181, C182, C183, C184, C185, C186, C187, C188, C189, C190, C191, C192, C193, C194, C195, C196, C197, C198, C199, C200, C201, C202, C203, C204, C205, C206, C207, C208, C209, C210, C211, C212, C213, C214, C215, C216, C217, C218, C219, C220, C221, C222, C223, C224, C225, C226, C227, C228, C229, C230, C231, C232, C233, C234, C235, C236, C237, C238, C239, C240, C241, C242, C243, C244, C245, C246, C247, C248, C249, C250: 0.1u; C_0402_1005Metric; LCSC Part # C1525
U2, U3, U4, U5, U6, U7, U8, U9, U10, U11, U12, U13, U14, U15, U16, U17, U18, U19, U20, U21, U22, U23, U24, U25, U26, U27, U28, U29, U30, U31, U32, U33, U34, U35, U36, U37, U38, U39, U40, U41, U42, U43, U44, U45, U46, U47, U48, U49, U50, U51, U52, U53, U54, U55, U56, U57, U58, U59, U60, U61, U62, U63, U64, U65, U66, U67, U68, U69, U70, U71, U72, U73, U74, U75, U76, U77, U78, U79, U80, U81, U82, U83, U84, U85, U86, U87, U88, U89, U90, U91, U92, U93, U94, U95, U96, U97, U98, U99, U100, U101, U102, U103, U104, U105, U106, U107, U108, U109, U110, U111, U112, U113, U114, U115, U116, U117, U118, U119, U120, U121, U122, U123, U124, U125, U126, U127, U128, U129, U130, U131, U132, U133, U134, U135, U136, U137, U138, U139, U140, U141, U142, U143, U144, U145, U146, U147, U148, U149, U150, U151, U152, U153, U154, U155, U156, U157, U158, U159, U160, U161, U162, U163, U164, U165, U166, U167, U168, U169, U170, U171, U172, U173, U174, U175, U176, U177, U178, U179, U180, U181, U182, U183, U184, U185, U186, U187, U188, U189, U190, U191, U192, U193, U194, U195, U196, U197, U198, U199, U200, U201, U202, U203, U204, U205, U206, U207, U208, U209: AH49HSC; SOT-23-3; LCSC Part # C510723

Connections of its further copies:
3.3V: C43.2, C44.2, C45.2, C46.2, C47.2, C48.2, C49.2, C50.2, C51.2, C52.2, C53.2, C54.2, C55.2, C56.2, C57.2, C58.2, C59.2, C60.2, C61.2, C62.2, C63.2, C64.2, C65.2, C66.2, C67.2, C68.2, C69.2, C70.2, C71.2, C72.2, C73.2, C74.2, C75.2, C76.2, C77.2, C78.2, C79.2, C80.2, C81.2, C82.2, C83.2, C84.2, C85.2, C86.2, C87.2, C88.2, C89.2, C90.2, C91.2, C92.2, C93.2, C94.2, C95.2, C96.2, C97.2, C98.2, C99.2, C100.2, C101.2, C102.2, C103.2, C104.2, C105.2, C106.2, C107.2, C108.2, C109.2, C110.2, C111.2, C112.2, C113.2, C114.2, C115.2, C116.2, C117.2, C118.2, C119.2, C120.2, C121.2, C122.2, C123.2, C124.2, C125.2, C126.2, C127.2, C128.2, C129.2, C130.2, C131.2, C132.2, C133.2, C134.2, C135.2, C136.2, C137.2, C138.2, C139.2, C140.2, C141.2, C142.2, C143.2, C144.2, C145.2, C146.2, C147.2, C148.2, C149.2, C150.2, C151.2, C152.2, C153.2, C154.2, C155.2, C156.2, C157.2, C158.2, C159.2, C160.2, C161.2, C162.2, C163.2, C164.2, C165.2, C166.2, C167.2, C168.2, C169.2, C170.2, C171.2, C172.2, C173.2, C174.2, C175.2, C176.2, C177.2, C178.2, C179.2, C180.2, C181.2, C182.2, C183.2, C184.2, C185.2, C186.2, C187.2, C188.2, C189.2, C190.2, C191.2, C192.2, C193.2, C194.2, C195.2, C196.2, C197.2, C198.2, C199.2, C200.2, C201.2, C202.2, C203.2, C204.2, C205.2, C206.2, C207.2, C208.2, C209.2, C210.2, C211.2, C212.2, C213.2, C214.2, C215.2, C216.2, C217.2, C218.2, C219.2, C220.2, C221.2, C222.2, C223.2, C224.2, C225.2, C226.2, C227.2, C228.2, C229.2, C230.2, C231.2, C232.2, C233.2, C234.2, C235.2, C236.2, C237.2, C238.2, C239.2, C240.2, C241.2, C242.2, C243.2, C244.2, C245.2, C246.2, C247.2, C248.2, C249.2, C250.2, U2.1 (VCC), U3.1 (VCC), U4.1 (VCC), U5.1 (VCC), U6.1 (VCC), U7.1 (VCC), U8.1 (VCC), U9.1 (VCC), U10.1 (VCC), U11.1 (VCC), U12.1 (VCC), U13.1 (VCC), U14.1 (VCC), U15.1 (VCC), U16.1 (VCC), U17.1 (VCC), U18.1 (VCC), U19.1 (VCC), U20.1 (VCC), U21.1 (VCC), U22.1 (VCC), U23.1 (VCC), U24.1 (VCC), U25.1 (VCC), U26.1 (VCC), U27.1 (VCC), U28.1 (VCC), U29.1 (VCC), U30.1 (VCC), U31.1 (VCC), U32.1 (VCC), U33.1 (VCC), U34.1 (VCC), U35.1 (VCC), U36.1 (VCC), U37.1 (VCC), U38.1 (VCC), U39.1 (VCC), U40.1 (VCC), U41.1 (VCC), U42.1 (VCC), U43.1 (VCC), U44.1 (VCC), U45.1 (VCC), U46.1 (VCC), U47.1 (VCC), U48.1 (VCC), U49.1 (VCC), U50.1 (VCC), U51.1 (VCC), U52.1 (VCC), U53.1 (VCC), U54.1 (VCC), U55.1 (VCC), U56.1 (VCC), U57.1 (VCC), U58.1 (VCC), U59.1 (VCC), U60.1 (VCC), U61.1 (VCC), U62.1 (VCC), U63.1 (VCC), U64.1 (VCC), U65.1 (VCC), U66.1 (VCC), U67.1 (VCC), U68.1 (VCC), U69.1 (VCC), U70.1 (VCC), U71.1 (VCC), U72.1 (VCC), U73.1 (VCC), U74.1 (VCC), U75.1 (VCC), U76.1 (VCC), U77.1 (VCC), U78.1 (VCC), U79.1 (VCC), U80.1 (VCC), U81.1 (VCC), U82.1 (VCC), U83.1 (VCC), U84.1 (VCC), U85.1 (VCC), U86.1 (VCC), U87.1 (VCC), U88.1 (VCC), U89.1 (VCC), U90.1 (VCC), U91.1 (VCC), U92.1 (VCC), U93.1 (VCC), U94.1 (VCC), U95.1 (VCC), U96.1 (VCC), U97.1 (VCC), U98.1 (VCC), U99.1 (VCC), U100.1 (VCC), U101.1 (VCC), U102.1 (VCC), U103.1 (VCC), U104.1 (VCC), U105.1 (VCC), U106.1 (VCC), U107.1 (VCC), U108.1 (VCC), U109.1 (VCC), U110.1 (VCC), U111.1 (VCC), U112.1 (VCC), U113.1 (VCC), U114.1 (VCC), U115.1 (VCC), U116.1 (VCC), U117.1 (VCC), U118.1 (VCC), U119.1 (VCC), U120.1 (VCC), U121.1 (VCC), U122.1 (VCC), U123.1 (VCC), U124.1 (VCC), U125.1 (VCC), U126.1 (VCC), U127.1 (VCC), U128.1 (VCC), U129.1 (VCC), U130.1 (VCC), U131.1 (VCC), U132.1 (VCC), U133.1 (VCC), U134.1 (VCC), U135.1 (VCC), U136.1 (VCC), U137.1 (VCC), U138.1 (VCC), U139.1 (VCC), U140.1 (VCC), U141.1 (VCC), U142.1 (VCC), U143.1 (VCC), U144.1 (VCC), U145.1 (VCC), U146.1 (VCC), U147.1 (VCC), U148.1 (VCC), U149.1 (VCC), U150.1 (VCC), U151.1 (VCC), U152.1 (VCC), U153.1 (VCC), U154.1 (VCC), U155.1 (VCC), U156.1 (VCC), U157.1 (VCC), U158.1 (VCC), U159.1 (VCC), U160.1 (VCC), U161.1 (VCC), U162.1 (VCC), U163.1 (VCC), U164.1 (VCC), U165.1 (VCC), U166.1 (VCC), U167.1 (VCC), U168.1 (VCC), U169.1 (VCC), U170.1 (VCC), U171.1 (VCC), U172.1 (VCC), U173.1 (VCC), U174.1 (VCC), U175.1 (VCC), U176.1 (VCC), U177.1 (VCC), U178.1 (VCC), U179.1 (VCC), U180.1 (VCC), U181.1 (VCC), U182.1 (VCC), U183.1 (VCC), U184.1 (VCC), U185.1 (VCC), U186.1 (VCC), U187.1 (VCC), U188.1 (VCC), U189.1 (VCC), U190.1 (VCC), U191.1 (VCC), U192.1 (VCC), U193.1 (VCC), U194.1 (VCC), U195.1 (VCC), U196.1 (VCC), U197.1 (VCC), U198.1 (VCC), U199.1 (VCC), U200.1 (VCC), U201.1 (VCC), U202.1 (VCC), U203.1 (VCC), U204.1 (VCC), U205.1 (VCC), U206.1 (VCC), U207.1 (VCC), U208.1 (VCC), U209.1 (VCC); also elsewhere on the board
/sensor column0/sensor1/OUT: U20.2 (OUT); also elsewhere on the board
/sensor column0/sensor2/OUT: U39.2 (OUT); also elsewhere on the board
/sensor column0/sensor3/OUT: U58.2 (OUT); also elsewhere on the board
/sensor column0/sensor4/OUT: U77.2 (OUT); also elsewhere on the board
/sensor column0/sensor5/OUT: U96.2 (OUT); also elsewhere on the board
/sensor column0/sensor6/OUT: U115.2 (OUT); also elsewhere on the board
/sensor column0/sensor7/OUT: U134.2 (OUT); also elsewhere on the board
/sensor column0/sensor8/OUT: U153.2 (OUT); also elsewhere on the board
/sensor column0/sensor9/OUT: U172.2 (OUT); also elsewhere on the board
/sensor column0/sensor10/OUT: U191.2 (OUT); also elsewhere on the board
/sensor column1/sensor0/OUT: U2.2 (OUT); also elsewhere on the board
/sensor column1/sensor1/OUT: U21.2 (OUT); also elsewhere on the board
/sensor column1/sensor2/OUT: U40.2 (OUT); also elsewhere on the board
/sensor column1/sensor3/OUT: U59.2 (OUT); also elsewhere on the board
/sensor column1/sensor4/OUT: U78.2 (OUT); also elsewhere on the board
/sensor column1/sensor5/OUT: U97.2 (OUT); also elsewhere on the board
/sensor column1/sensor6/OUT: U116.2 (OUT); also elsewhere on the board
/sensor column1/sensor7/OUT: U135.2 (OUT); also elsewhere on the board
/sensor column1/sensor8/OUT: U154.2 (OUT); also elsewhere on the board
/sensor column1/sensor9/OUT: U173.2 (OUT); also elsewhere on the board
/sensor column1/sensor10/OUT: U192.2 (OUT); also elsewhere on the board
/sensor column2/sensor0/OUT: U3.2 (OUT); also elsewhere on the board
/sensor column2/sensor1/OUT: U22.2 (OUT); also elsewhere on the board
/sensor column2/sensor2/OUT: U41.2 (OUT); also elsewhere on the board
/sensor column2/sensor3/OUT: U60.2 (OUT); also elsewhere on the board
/sensor column2/sensor4/OUT: U79.2 (OUT); also elsewhere on the board
/sensor column2/sensor5/OUT: U98.2 (OUT); also elsewhere on the board
/sensor column2/sensor6/OUT: U117.2 (OUT); also elsewhere on the board
/sensor column2/sensor7/OUT: U136.2 (OUT); also elsewhere on the board
/sensor column2/sensor8/OUT: U155.2 (OUT); also elsewhere on the board
/sensor column2/sensor9/OUT: U174.2 (OUT); also elsewhere on the board
/sensor column2/sensor10/OUT: U193.2 (OUT); also elsewhere on the board
/sensor column3/sensor0/OUT: U4.2 (OUT); also elsewhere on the board
/sensor column3/sensor1/OUT: U23.2 (OUT); also elsewhere on the board
/sensor column3/sensor2/OUT: U42.2 (OUT); also elsewhere on the board
/sensor column3/sensor3/OUT: U61.2 (OUT); also elsewhere on the board
/sensor column3/sensor4/OUT: U80.2 (OUT); also elsewhere on the board
/sensor column3/sensor5/OUT: U99.2 (OUT); also elsewhere on the board
/sensor column3/sensor6/OUT: U118.2 (OUT); also elsewhere on the board
/sensor column3/sensor7/OUT: U137.2 (OUT); also elsewhere on the board
/sensor column3/sensor8/OUT: U156.2 (OUT); also elsewhere on the board
/sensor column3/sensor9/OUT: U175.2 (OUT); also elsewhere on the board
/sensor column3/sensor10/OUT: U194.2 (OUT); also elsewhere on the board
/sensor column4/sensor0/OUT: U5.2 (OUT); also elsewhere on the board
/sensor column4/sensor1/OUT: U24.2 (OUT); also elsewhere on the board
/sensor column4/sensor2/OUT: U43.2 (OUT); also elsewhere on the board
/sensor column4/sensor3/OUT: U62.2 (OUT); also elsewhere on the board
/sensor column4/sensor4/OUT: U81.2 (OUT); also elsewhere on the board
/sensor column4/sensor5/OUT: U100.2 (OUT); also elsewhere on the board
/sensor column4/sensor6/OUT: U119.2 (OUT); also elsewhere on the board
/sensor column4/sensor7/OUT: U138.2 (OUT); also elsewhere on the board
/sensor column4/sensor8/OUT: U157.2 (OUT); also elsewhere on the board
/sensor column4/sensor9/OUT: U176.2 (OUT); also elsewhere on the board
/sensor column4/sensor10/OUT: U195.2 (OUT); also elsewhere on the board
/sensor column5/sensor0/OUT: U6.2 (OUT); also elsewhere on the board
/sensor column5/sensor1/OUT: U25.2 (OUT); also elsewhere on the board
/sensor column5/sensor2/OUT: U44.2 (OUT); also elsewhere on the board
/sensor column5/sensor3/OUT: U63.2 (OUT); also elsewhere on the board
/sensor column5/sensor4/OUT: U82.2 (OUT); also elsewhere on the board
/sensor column5/sensor5/OUT: U101.2 (OUT); also elsewhere on the board
/sensor column5/sensor6/OUT: U120.2 (OUT); also elsewhere on the board
/sensor column5/sensor7/OUT: U139.2 (OUT); also elsewhere on the board
/sensor column5/sensor8/OUT: U158.2 (OUT); also elsewhere on the board
/sensor column5/sensor9/OUT: U177.2 (OUT); also elsewhere on the board
/sensor column5/sensor10/OUT: U196.2 (OUT); also elsewhere on the board
/sensor column6/sensor0/OUT: U7.2 (OUT); also elsewhere on the board
/sensor column6/sensor1/OUT: U26.2 (OUT); also elsewhere on the board
/sensor column6/sensor2/OUT: U45.2 (OUT); also elsewhere on the board
/sensor column6/sensor3/OUT: U64.2 (OUT); also elsewhere on the board
/sensor column6/sensor4/OUT: U83.2 (OUT); also elsewhere on the board
/sensor column6/sensor5/OUT: U102.2 (OUT); also elsewhere on the board
/sensor column6/sensor6/OUT: U121.2 (OUT); also elsewhere on the board
/sensor column6/sensor7/OUT: U140.2 (OUT); also elsewhere on the board
/sensor column6/sensor8/OUT: U159.2 (OUT); also elsewhere on the board
/sensor column6/sensor9/OUT: U178.2 (OUT); also elsewhere on the board
/sensor column6/sensor10/OUT: U197.2 (OUT); also elsewhere on the board
/sensor column7/sensor0/OUT: U8.2 (OUT); also elsewhere on the board
/sensor column7/sensor1/OUT: U27.2 (OUT); also elsewhere on the board
/sensor column7/sensor2/OUT: U46.2 (OUT); also elsewhere on the board
/sensor column7/sensor3/OUT: U65.2 (OUT); also elsewhere on the board
/sensor column7/sensor4/OUT: U84.2 (OUT); also elsewhere on the board
/sensor column7/sensor5/OUT: U103.2 (OUT); also elsewhere on the board
/sensor column7/sensor6/OUT: U122.2 (OUT); also elsewhere on the board
/sensor column7/sensor7/OUT: U141.2 (OUT); also elsewhere on the board
/sensor column7/sensor8/OUT: U160.2 (OUT); also elsewhere on the board
/sensor column7/sensor9/OUT: U179.2 (OUT); also elsewhere on the board
/sensor column7/sensor10/OUT: U198.2 (OUT); also elsewhere on the board
/sensor column8/sensor0/OUT: U9.2 (OUT); also elsewhere on the board
/sensor column8/sensor1/OUT: U28.2 (OUT); also elsewhere on the board
/sensor column8/sensor2/OUT: U47.2 (OUT); also elsewhere on the board
/sensor column8/sensor3/OUT: U66.2 (OUT); also elsewhere on the board
/sensor column8/sensor4/OUT: U85.2 (OUT); also elsewhere on the board
/sensor column8/sensor5/OUT: U104.2 (OUT); also elsewhere on the board
/sensor column8/sensor6/OUT: U123.2 (OUT); also elsewhere on the board
/sensor column8/sensor7/OUT: U142.2 (OUT); also elsewhere on the board
/sensor column8/sensor8/OUT: U161.2 (OUT); also elsewhere on the board
/sensor column8/sensor9/OUT: U180.2 (OUT); also elsewhere on the board
/sensor column8/sensor10/OUT: U199.2 (OUT); also elsewhere on the board
/sensor column9/sensor0/OUT: U10.2 (OUT); also elsewhere on the board
/sensor column9/sensor1/OUT: U29.2 (OUT); also elsewhere on the board
/sensor column9/sensor2/OUT: U48.2 (OUT); also elsewhere on the board
/sensor column9/sensor3/OUT: U67.2 (OUT); also elsewhere on the board
/sensor column9/sensor4/OUT: U86.2 (OUT); also elsewhere on the board
/sensor column9/sensor5/OUT: U105.2 (OUT); also elsewhere on the board
/sensor column9/sensor6/OUT: U124.2 (OUT); also elsewhere on the board
/sensor column9/sensor7/OUT: U143.2 (OUT); also elsewhere on the board
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

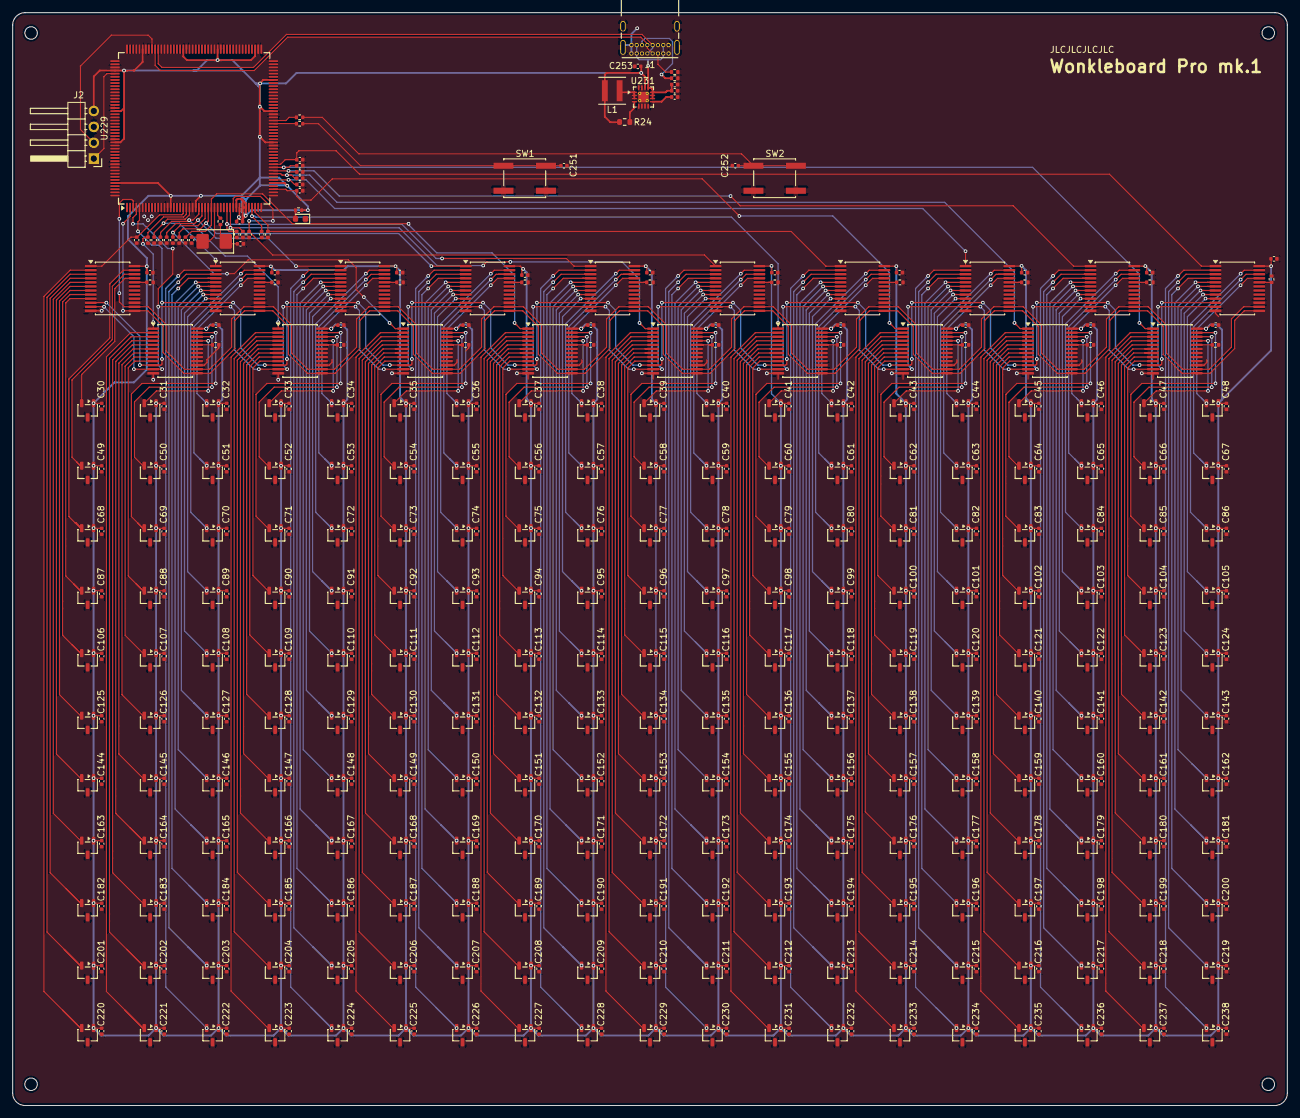
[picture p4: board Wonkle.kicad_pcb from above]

Board: 2 copper layers, 204.0 x 174.9 mm, 519 parts (0 on the bottom side), 271 nets.

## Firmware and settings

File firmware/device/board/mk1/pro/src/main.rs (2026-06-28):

#![allow(static_mut_refs)]
#![no_main]
#![no_std]

use defmt_rtt as _;
// See https://defmt.ferrous-systems.com/global-logger for more information
use panic_probe as _; // Print panic message to probe console
use stm32f4xx_hal::{otg_fs, pac, prelude::*, rcc::Config};
use wonkle::{profiler, sensor, tablet, telemetry, usb};

const USB_ENUMERATION_DELAY_MS: u32 = 3000;

#[cortex_m_rt::entry]
fn main() -> ! {
    defmt::info!("Hello from Wonkle!");

    let dp = pac::Peripherals::take().unwrap(); // device peripheral
    let mut cp = cortex_m::peripheral::Peripherals::take().unwrap(); // core peripheral
    let mut rcc = dp.RCC.freeze(
        Config::hsi()
            .sysclk(84.MHz()) // HCLK
            .pclk1(42.MHz()) // APB1
            .pclk2(84.MHz()) // APB2
            .require_pll48clk(), // PLL
    );

    profiler::enable_cycle_counter(&mut cp.DCB, &mut cp.DWT);

    let gpioa = dp.GPIOA.split(&mut rcc);
    let gpioc = dp.GPIOC.split(&mut rcc);
    let gpioe = dp.GPIOE.split(&mut rcc);
    let gpiof = dp.GPIOF.split(&mut rcc);

    // sensor input pins
    let _ = gpioa.pa1.into_analog();
    let _ = gpioa.pa2.into_analog();
    let _ = gpioa.pa3.into_analog();
    let _ = gpioa.pa4.into_analog();
    let _ = gpioa.pa6.into_analog();
    let _ = gpioa.pa7.into_analog();
    let _ = gpioc.pc1.into_analog();
    let _ = gpioc.pc2.into_analog();
    let _ = gpioc.pc3.into_analog();
    let _ = gpioc.pc4.into_analog();
    let _ = gpioc.pc5.into_analog();
    let _ = gpiof.pf3.into_analog();
    let _ = gpiof.pf4.into_analog();
    let _ = gpiof.pf5.into_analog();
    let _ = gpiof.pf6.into_analog();
    let _ = gpiof.pf7.into_analog();
    let _ = gpiof.pf8.into_analog();
    let _ = gpiof.pf9.into_analog();
    let _ = gpiof.pf10.into_analog();

    let mux: sensor::MuxSelect = (
        gpioe.pe6.into_push_pull_output(),
        gpioe.pe5.into_push_pull_output(),
        gpioe.pe4.into_push_pull_output(),
        gpioe.pe3.into_push_pull_output(),
    )
        .outport();

    let usb_peripheral = otg_fs::USB::new(
        (dp.OTG_FS_GLOBAL, dp.OTG_FS_DEVICE, dp.OTG_FS_PWRCLK),
        (gpioa.pa11, gpioa.pa12),
        &rcc.clocks,
    );

    defmt::info!(
        "Waiting {}ms for USB enumeration...",
        USB_ENUMERATION_DELAY_MS
    );
    cp.SYST
        .delay(&rcc.clocks)
        .delay_ms(USB_ENUMERATION_DELAY_MS);

    defmt::info!("Initializing...");
    let mut usb_device = usb::build(usb_peripheral);
    let mut sensor_grid = sensor::SensorGrid::new(dp.ADC2, dp.ADC3, mux, &mut rcc);
    let mut profiler = profiler::PerformanceProfiler::new(rcc.clocks.sysclk().raw());
    profiler.init();
    let mut telemetry = telemetry::Telemetry::new();
    let mut tablet = tablet::Tablet::new();
    let mut grid_buffer = [0u16; sensor::SENSOR_COUNT];

    defmt::info!("Initialized!");
    defmt::info!(
        "Config: mux_settling={}, adc_sampling={}, re_reads={}",
        sensor_grid.mux_settling(),
        sensor::adc_sampling_label(sensor_grid.adc_sampling()),
        sensor_grid.adc_re_reads()
    );
    defmt::info!(
        "Filters: ema_alpha_per_mille={}",
        sensor_grid.ema_alpha() * 1000.0
    );

    loop {
        profiler.begin(true);

        // Pump USB first so CDC RX is fresh for the host commands, then dispatch any commands.
        usb_device.poll();
        telemetry.service(&mut usb_device, &mut sensor_grid, &profiler);
        profiler.mark_telemetry_service();

        sensor_grid.scan_grid(&mut grid_buffer);
        profiler.mark_scan();
        profiler.record_scan_details(sensor_grid.last_scan_timing());

        let mut cursor = tablet.find_centroid(&grid_buffer);
        profiler.mark_centroid();

        tablet.update_cursor(&sensor_grid, &mut cursor, &usb_device);
        profiler.mark_usb();
        profiler.report_if_due();

        telemetry.feed_grid(
            &grid_buffer,
            cursor.x,
            cursor.y,
            cursor.valid,
            &mut usb_device,
        );
    }
}

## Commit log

2026-05-29 Update PCB with HSE oscillator, Footprint Mismatch fix and Rename project files to Wonkle (#36)
    [Wonkle.kicad_pcb, Wonkle.kicad_sch, pompyboard.kicad_pcb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]
2026-05-29 put mk1 hardware design under its own subdirectory
    [Wonkle.kicad_pcb, Wonkle.kicad_sch, sensor.kicad_sch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]
2026-05-29 init wonkleboard mk.1 lite as empty atopile project
    [default.kicad_pcb]
2026-06-01 pcb: add basic STM32F429 MCU module
    [C0402_L1.0-W0.5-H0.5.step, R0402_L1.0-W0.5-H0.4.step, SOT-23-3L_L2.9-W1.6-H1.1-LS2.8-P0.95.step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]
2026-06-04 create space to redesign wonkleboard mk.1 pro with atopile
    [Wonkle.kicad_pcb, Wonkle.kicad_sch, sensor.kicad_sch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]
2026-06-04 pcb: initialize Wonkleboard mk.1 Pro atopile project
    [default.kicad_pcb]
2026-06-04 pcb: make atopile source code consistent
2026-06-04 pcb: make CI build more robust
2026-06-05 pcb: remove unnecessary pragma directives
2026-06-05 pcb: add MCU to Wonkleboard mk.1 Pro
    [C0402_L1.0-W0.5-H0.5.step, R0402_L1.0-W0.5-H0.4.step, default.kicad_pcb]
2026-06-16 firmware: update stm32f4xx-hal
2026-06-22 pcb: add MUX and sensors to Wonkleboard mk.1 Pro
    [default.kicad_pcb]
2026-06-22 pcb: oops forgot to commit this
    [default.kicad_pcb]
2026-06-23 pcb: add buck converter
    [C0402_L1.0-W0.5-H0.5.step, C0603_L1.6-W0.8-H0.8.step, C0805_L2.0-W1.3-H1.3.step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]
2026-06-23 pcb: add STM32 ADC application note
2026-06-24 pcb: document ADC-capable pins
2026-06-24 pcb: add more bookmarks for STM32F429 datasheet and reference manual
2026-06-25 pcb: add more references to documentation
2026-06-25 pcb: add decoupling capacitors to STM32F429
    [C0402_L1.0-W0.5-H0.5.step, default.kicad_pcb]
2026-06-27 pcb: migrate from atopile to tscircuit (tsci init)
    [C0402_L1.0-W0.5-H0.5.step, C0603_L1.6-W0.8-H0.8.step, C0805_L2.0-W1.3-H1.3.step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]
2026-06-27 pcb: add STM32F429IGT6
2026-06-27 pcb: add PDF files to gitignore
2026-06-27 pcb: add KiCad files to gitignore
2026-06-27 pcb: check formatting in CI
2026-06-27 pcb: add JLCPCB link to imports
2026-06-27 pcb: add AH49HSC
2026-06-27 pcb: add CD74HC4067SM96
2026-06-27 pcb: add TPS62152RGTR
2026-06-27 pcb: sort imports
2026-06-27 pcb: add sensor array
2026-06-27 pcb: improve STM32F429IGT6 pin labeling
2026-06-27 pcb: abstract out processor module
2026-06-27 pcb: add pinAttributes
2026-06-27 pcb: fix erroneous clearance error (remove when https://github.com/tscircuit/circuit-json-util/pull/101 gets released)
2026-06-27 ci: update PCB build command
2026-06-28 pcb: improve schematic design
2026-06-28 pcb: add USB port
2026-06-28 firmware: make space for firmware for other devices
2026-07-13 remove tscircuit and revert to just KiCad because none of the pcb-as-code are good enough just yet
    [Wonkle.kicad_pcb, Wonkle.kicad_sch, sensor.kicad_sch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]
